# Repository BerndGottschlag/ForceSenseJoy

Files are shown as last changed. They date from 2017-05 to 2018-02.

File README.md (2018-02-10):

# ForceSenseJoy

This joystick measures the force applied by the user and not the deflection as done by conventional joysticks.
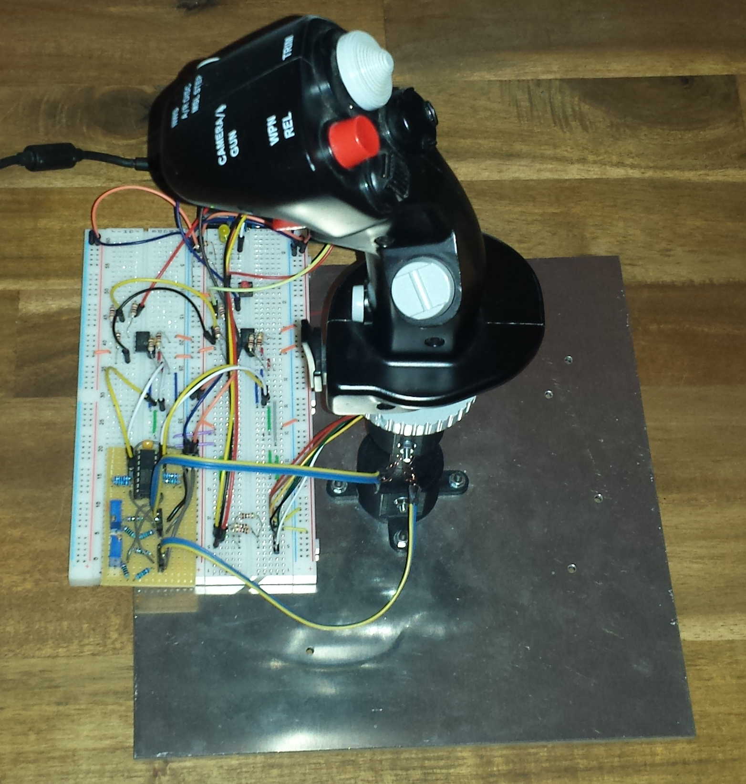
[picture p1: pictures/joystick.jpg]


## Operating principle

The force is measured using two strain gauges each for the x- and y-axis.
These strain gauges are used in a half-bridge Wheatstone bridge configuration.
The signal from the bridge are amplified by an instrumentation amplifier and then read out using 13-bit analog-digital-converters.
The LUFA library is used to create a USB-joystick device.

## Status

At the moment there are some problems.
The calibration of the Wheatstone bridges is far from perfect.
On one hand this leads to a laborious adjustment process using the trim pots to balance the arms of the bridge and on the other hand the signal sometimes drifts over time.
While the adjustment does not have to be perfect, as the center point (zero) can be set via software on the press of a button,
a bigger imbalance of the bridges will make the amplifier to be unable to amplify the signal to its maximum amplitude.
A possible sollution to this would be the adjustment of the reference voltage.

## How to build
The make script is situated in firmware/src/.  
The project can be build and flashed with
```
make avrdude
```

## License

This project is licensed under the MIT License - see the [LICENSE](LICENSE) file for details

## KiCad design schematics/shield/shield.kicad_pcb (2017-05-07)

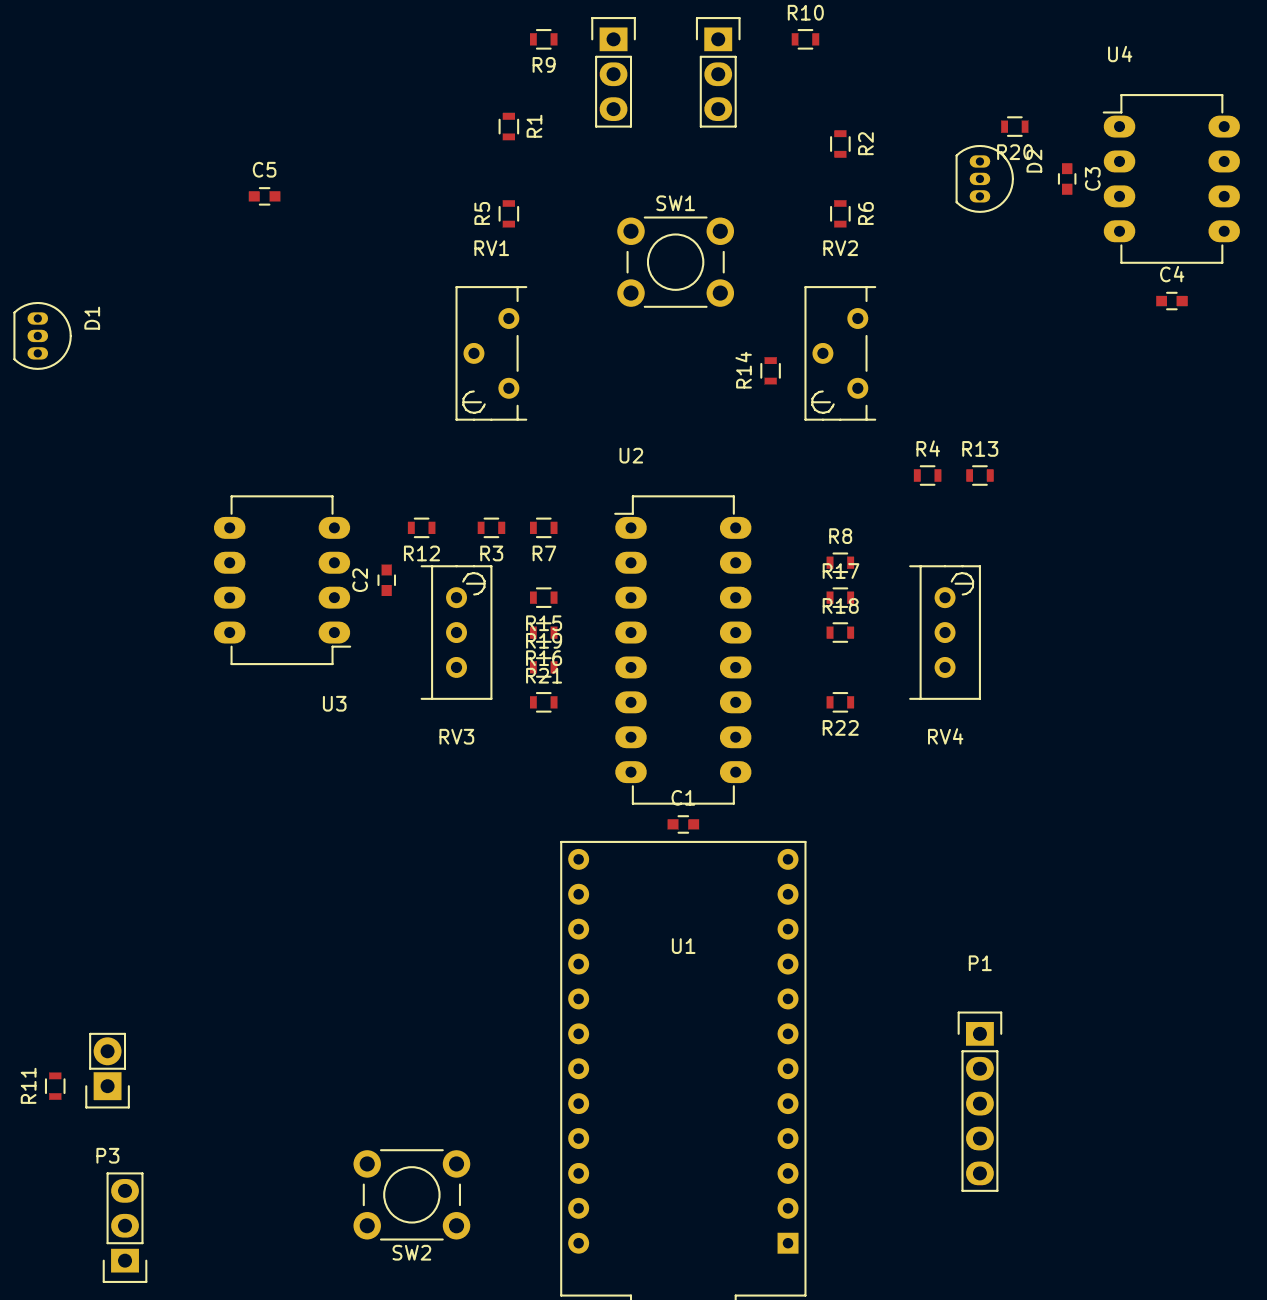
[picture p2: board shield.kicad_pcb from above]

Board: 2 copper layers, 44 parts (0 on the bottom side), 45 nets, no tracks yet.

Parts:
C1, C4, C5: 1 uF; C_0603
C2, C3: 0.47uF; C_0603
D1, D2: LM385LP‑1‑2; TO-92_Inline_Narrow_Oval
P1: CONN_01X05; Pin_Header_Straight_1x05
P2, P4, P5: CONN_01X03; Pin_Header_Straight_1x03
P3: CONN_01X02; Pin_Header_Straight_1x02
R1, R2, R3, R4, R5, R6, R7, R8, R15, R17: 0; R_0603
R9, R10: 345; R_0603
R11: R; R_0603
R12, R13: 350; R_0603
R14: 10k; R_0603
R16, R18: 80; R_0603
R19, R20: 1K; R_0603
R21, R22: 1k; R_0603
RV1, RV2: 10; Potentiometer_Bourns_3296Y_3-8Zoll_Angular_ScrewUp
RV3, RV4: 100; Potentiometer_Bourns_3296W_3-8Zoll_Inline_ScrewUp
SW1, SW2: SW_PUSH; SW_PUSH_6mm
U1: ArduinoProMicro
U2: INA2126; DIP-16_W7.62mm_LongPads
U3, U4: MCP3301; DIP-8_W7.62mm_LongPads

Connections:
+5V: C1.2, C4.2, C5.2, P1.5, P2.3, P4.1, P5.1, R9.1, R10.1, SW1.1, U1.21, U2.9, U3.8, U4.8
Analog_out: P2.1, U1.17
CLK: U1.16, U3.7, U4.7
CLK_Shift: P1.2, U1.6
CS-A: U1.11, U3.5
CS-B: U1.12, U4.5
DATA_Shift: P1.1, U1.7
D_Out: U1.15, U3.6, U4.6
GND: C1.1, C4.1, C5.1, D1.2, D2.2, P1.4, P2.2, P4.3, P5.3, R11.1, R12.2, R13.2, R14.2, U1.3, U2.8, U3.4, U4.4
LATCH: P1.3, U1.5
LED: P3.2, U1.13
unnamed: C2.1, R21.1, U3.2
unnamed: C2.2, R19.1, U3.3
unnamed: C3.1, R22.1, U4.2
unnamed: C3.2, R20.1, U4.3
unnamed: P3.1, R11.2
unnamed: R1.1, R9.2
unnamed: R1.2, R5.2
unnamed: R2.2, R6.2
unnamed: R3.1, R7.2
unnamed: R4.1, R8.2
unnamed: R5.1, RV1.3
unnamed: R6.1, RV2.3
unnamed: R2.1, R10.2
unnamed: R3.2, R12.1
unnamed: R4.2, R13.1
unnamed: R14.1, SW1.2, U1.10
unnamed: R15.1, U2.3
unnamed: R15.2, RV3.1
unnamed: R16.1, U2.4
unnamed: R16.2, RV3.2
unnamed: R17.1, U2.14
unnamed: R17.2, RV4.1
unnamed: R18.1, U2.13
unnamed: R18.2, RV4.2
unnamed: SW2.1, U1.23
unnamed: SW2.2, U1.22
RefA: D1.1, R19.2, U2.5, U3.1
RefB: D2.1, R20.2, U4.1
V+inA: R7.1, RV1.2, U2.2
V+inB: R8.1, RV2.2, U2.15
V-inA: P4.2, U2.1
V-inB: P5.2, U2.16
VoutA: R21.2, U2.6, U2.7
VoutB: R22.2, U2.10, U2.11

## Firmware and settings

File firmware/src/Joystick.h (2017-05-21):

/*
             LUFA Library
     Copyright (C) Dean Camera, 2015.

  dean [at] fourwalledcubicle [dot] com
           www.lufa-lib.org
*/

/*
  Copyright 2015  Dean Camera (dean [at] fourwalledcubicle [dot] com)
  Copyright 2017  Bernd Gottschlag

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
  The author disclaims all warranties with regard to this
  software, including all implied warranties of merchantability
  and fitness.  In no event shall the author be liable for any
  special, indirect or consequential damages or any damages
  whatsoever resulting from loss of use, data or profits, whether
  in an action of contract, negligence or other tortious action,
  arising out of or in connection with the use or performance of
  this software.
*/

/** \file
 *
 *  Header file for Joystick.c.
 */

#ifndef _JOYSTICK_H_
#define _JOYSTICK_H_

	/* Includes: */
		#include <avr/io.h>
		#include <avr/wdt.h>
		#include <avr/power.h>
		#include <avr/interrupt.h>
		#include <string.h>

		#include "Descriptors.h"

		//#include <LUFA/Drivers/Board/Joystick.h>
		#include <LUFA/Drivers/Board/LEDs.h>
		//#include <LUFA/Drivers/Board/Buttons.h>
		#include <LUFA/Drivers/USB/USB.h>
		#include <LUFA/Platform/Platform.h>

	/* Type Defines: */
		/** Type define for the joystick HID report structure, for creating and sending HID reports to the host PC.
		 *  This mirrors the layout described to the host in the HID report descriptor, in Descriptors.c.
		 */
		typedef struct
		{
			int16_t  X; /**< Current absolute joystick X position, as a signed 8-bit integer */
			int16_t  Y; /**< Current absolute joystick Y position, as a signed 8-bit integer */
			int16_t  Z; /**< Current absolute joystick Z position, as a signed 8-bit integer */
			//uint32_t Button; /**< Bit mask of the currently pressed joystick buttons */
			uint8_t Button1;
			uint8_t Button2;
			uint8_t Button3;
		} USB_JoystickReport_Data_t;

	/* Macros: */
		/** LED mask for the library LED driver, to indicate that the USB interface is not ready. */
		#define LEDMASK_USB_NOTREADY      LEDS_LED1

		/** LED mask for the library LED driver, to indicate that the USB interface is enumerating. */
		#define LEDMASK_USB_ENUMERATING  (LEDS_LED2 | LEDS_LED3)

		/** LED mask for the library LED driver, to indicate that the USB interface is ready. */
		#define LEDMASK_USB_READY        (LEDS_LED2 | LEDS_LED4)

		/** LED mask for the library LED driver, to indicate that an error has occurred in the USB interface. */
		#define LEDMASK_USB_ERROR        (LEDS_LED1 | LEDS_LED3)

	/* Function Prototypes: */
		void SetupHardware(void);

		void EVENT_USB_Device_Connect(void);
		void EVENT_USB_Device_Disconnect(void);
		void EVENT_USB_Device_ConfigurationChanged(void);
		void EVENT_USB_Device_ControlRequest(void);
		void EVENT_USB_Device_StartOfFrame(void);

		bool CALLBACK_HID_Device_CreateHIDReport(USB_ClassInfo_HID_Device_t* const HIDInterfaceInfo,
		                                         uint8_t* const ReportID,
		                                         const uint8_t ReportType,
		                                         void* ReportData,
		                                         uint16_t* const ReportSize);
		void CALLBACK_HID_Device_ProcessHIDReport(USB_ClassInfo_HID_Device_t* const HIDInterfaceInfo,
		                                          const uint8_t ReportID,
		                                          const uint8_t ReportType,
		                                          const void* ReportData,
		                                          const uint16_t ReportSize);

#endif

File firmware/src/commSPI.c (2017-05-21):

/*
  Copyright 2017 Bernd Gottschlag

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
  THE SOFTWARE IS PROVIDED "AS IS", WITHOUT WARRANTY OF ANY KIND, EXPRESS OR
  IMPLIED, INCLUDING BUT NOT LIMITED TO THE WARRANTIES OF MERCHANTABILITY, FITNESS
  FOR A PARTICULAR PURPOSE AND NONINFRINGEMENT. IN NO EVENT SHALL THE AUTHORS OR
  COPYRIGHT HOLDERS BE LIABLE FOR ANY CLAIM, DAMAGES OR OTHER LIABILITY, WHETHER
  IN AN ACTION OF CONTRACT, TORT OR OTHERWISE, ARISING FROM, OUT OF OR IN
  CONNECTION WITH THE SOFTWARE OR THE USE OR OTHER DEALINGS IN THE SOFTWARE.
 */

#if 0
Pinbelegung für SPI:		Pinout Leonardo 
SCK:		PB1		header
MOSI:		PB2		header
MISO:		PB3		header
SSA:		PB6		8
SSB:		PB7		9

#endif

#include <avr/io.h>
#include <util/delay.h>
#include <stdint.h>

// Portpin-Definitionen:
#define SCK		PB1
#define MOSI		PB2
#define MISO		PB3
#define SSA		PB6
#define SSB		PB7
#define latch		PF7	// for shift-in
#define CLKShift	PF5	// for shift-in
#define DataShift	PF6	// for shift-in
//#define LED		PB1	// LED für Debugging


void spiMasterInit(void)
{
	/* Set MOSI, SCK, SSA and SSB output, all others input */
	DDRB |= (1<<MOSI)|(1<<SCK)|(1<<SSA)|(1<<SSB);
	// Set MISO input
	DDRB &= ~(1<<MISO);
	/* Enable SPI, Master, set clock rate fck/2 */
	SPCR |= (1<<SPE)|(1<<MSTR)|(1<<SPI2X);
	//SPCR |= (1<<SPE)|(1<<MSTR)|(1<<SPR0);
	SPCR |= (1<<CPHA);		// Setup SPI for Mode 1

	// set SSA and SSB high (Transmission is initiated by pulling CS low)
	PORTB |= (1<<SSA)|(1<<SSB);

	// set latch-pin and clock-pin for shift-registers as output
	DDRF |= (1<<latch)|(1<<CLKShift);
	
	PORTF |= (1<<CLKShift);
	// set DataShift as input
	DDRF &= ~(1<<DataShift);
}



void spiMasterTransmit(char cData)
{
	/* Start transmission */
	SPDR = cData;
	/* Wait for transmission complete */
	while (!(SPSR & (1<<SPIF)));
}

uint8_t spiMasterReceive(void)
{
	SPDR = 0xff;				// writing to the SPDR makes transmitting before receiving unnessessary
	/* Wait for reception complete */
	while(!(SPSR & (1<<SPIF)));
	/* Return Data Register */
	return SPDR;
}

char spiMasterTranceive(char data)
{
	SPDR = data;			// transmit data
	while (!(SPSR & (1<<SPIF)));	// wait for end of transmission
	return SPDR;			// return received data
}

static void write_com(uint8_t data)
{
	spiMasterTransmit(data);				
}

void write_data(uint8_t data)
{
	spiMasterTransmit(data); 				
}

int16_t readData(uint8_t adcNo)
{
	uint8_t dataReceivedTemp;
	int16_t dataReceived;
	// set CS
	if (adcNo == 0)
	{
		PORTB &= ~(1<<SSA);
	}
	else
	{
		PORTB &= ~(1<<SSB);
	}
	dataReceivedTemp = spiMasterReceive();
	// Set unknown bits in front of NULL-bit to 0
	dataReceivedTemp &= ~(1<<6);
	dataReceivedTemp &= ~(1<<7);
	// Set Bit for sign and Delete the 13-bit sign if negative
	if ((dataReceivedTemp & (1<<4)) != 0)
	{
		// Set bits left of the old sign-bit to 1 to enlarge to 8 bits
		dataReceivedTemp |= (1<<5);
		dataReceivedTemp |= (1<<6);
		dataReceivedTemp |= (1<<7);
	}
	dataReceived = (dataReceivedTemp << 8);
	dataReceivedTemp = spiMasterReceive();
	dataReceived |= dataReceivedTemp;
	//dataReceived = (dataReceived << 3);
	// reset CS
	PORTB |= (1<<SSA)|(1<<SSB);
	return dataReceived;
}


uint8_t Bit_Reverse( uint8_t x ) 
{ 
	x = ((x >> 1) & 0x55) | ((x << 1) & 0xaa); 
	x = ((x >> 2) & 0x33) | ((x << 2) & 0xcc); 
	x = ((x >> 4) & 0x0f) | ((x << 4) & 0xf0); 
	return x;    
}

uint8_t shiftIn(void)
{	
	int8_t i;
	uint8_t dataIn = 0;

	for (i = 7; i >= 0; i--)
	{
		PORTF &= ~(1<<CLKShift);
		if(PINF & (1<<DataShift))
		{
			dataIn |= (1<<i);
		}
		else dataIn &= ~(1<<i);
		PORTF |= (1<<CLKShift);
	}
	dataIn = ~dataIn;
	return dataIn;
}

void readButtons(uint8_t* buttonState1, uint8_t* buttonState2, uint8_t* buttonState3)
{	
	int8_t buttonStateNonFlipped = 0;
	// latch data shift registers
	PORTF |= (1<<latch);
	_delay_ms(1);			//TODO: make smaller if possible
	PORTF &= ~(1<<latch);

	*buttonState1 = shiftIn();
	*buttonState2 = shiftIn();
	*buttonState3 = shiftIn();
	
	/* Flip all bytes */
	buttonStateNonFlipped = *buttonState1;
	*buttonState1 = Bit_Reverse(buttonStateNonFlipped);
	buttonStateNonFlipped = *buttonState2;
	*buttonState2 = Bit_Reverse(buttonStateNonFlipped);
	buttonStateNonFlipped = *buttonState3;
	*buttonState3 = Bit_Reverse(buttonStateNonFlipped);
	
	// Button 1 and 2 (bit 1 and 2 of buttonState1, starting with lsb) as is are not used, so after the first bit everything must be shifted left two places 
	if ((*buttonState1 & (1<<0)) != 0)
		*buttonState1 |= (1<<2);
	*buttonState1 = (*buttonState1 >> 2);
	if ((*buttonState2 & (1<<0)) != 0)
		*buttonState1 |= (1<<6);
	if ((*buttonState2 & (1<<1)) != 0)
		*buttonState1 |= (1<<7);
	*buttonState2 = (*buttonState2 >> 2);
	if ((*buttonState3 & (1<<0)) != 0)
		*buttonState2 |= (1<<6);
	if ((*buttonState3 & (1<<1)) != 0)
		*buttonState2 |= (1<<7);
	*buttonState3 = (*buttonState3 >> 2);
	
} 


void NOP(void)
{
	write_com(0x00);
}

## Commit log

2017-05-07 Initial commit without the LUFA-library
    [shield.kicad_pcb, shield.sch]
2017-05-07 Change symbol for the strain gauges
    [shield.sch]
2017-05-07 Change configuration of the trim-pots for the bridge
    This change effects a easier calibration as it is less sensitive to
    changes.
    Furthermore it also seems to eliminate a certain creeping of the signal
    that was present before.
    [shield.sch]
2017-05-21 Remove unused I2C-functions
2018-02-10 Clean up KiCad files
